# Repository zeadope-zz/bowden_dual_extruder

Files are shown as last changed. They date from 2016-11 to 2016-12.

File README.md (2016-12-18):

# bowden_dual_extruder
For more information check:
http://www.thingiverse.com/thing:1888865 - Bowden dual/quad extrusion extruder (single-nozzle single-drive) + video

This Repo exists so that anyone can enjoy this extruder.

### Printer firmware
In your printer's firmware (Marlin, Repetier or other) make sure you setup a delay for as long as it takes for your servo to move fully.
Also, make sure your printer will execute the servo G-Code on extruder switch.
I have added a working example of my Configuration.h from Repetier-Firmware.
For MarlinFirmware, follow the link above and find BigSteve's solution.

### Cura 15.04.6 - Easy option
For the older version, that still works fine, I have added a Configuration file you can simply load within Cura.
Before that, make sure your printer has 2 extruders in "Machine -> Machine settings... Extruder count [2]".
You will have to change the start2, end2 and pre and post switch G-Code to your printer's settings and Y-merger / Dual load/retract nozzle amount.

### Cura 2.3.1 Custom printer - The hard way but more powerful
I have included a configuration for Cura 2.3.1 that defines a custom printer with multiple extruders.
This also included definitions of these extruders and their specific settings for retraction and priming filament at tool change.
Cura 2.3.1 is awesome since the software allows you to select a material/extruder per STL. Even if you want to print a couple of the same single extrusion STL's you can do so. 
Also you can expand the number of extruders. For now I have set up 4 extruders. Since this Extruder design will allow RAMPS board owners to have 2 extruders stepper motors enabling the use of 4 filaments, instead of just 2 (one extruder per stepper motor).
With the Arduino Due and RAMPS-FD you can have a third extruder stepper motor for a total of 6 filaments.

*For Cura 2.3.1 all you have to do is change the extruder start and end G-Code within the custom printer definition file from Cura 2.3.1 to suit your printer.
And change the start and end G-Code of the extruders definition files from Cura 2.3.1 to suit your retraction and priming distances. This depends on the distance between the tip of the nozzle to the retract resting spot within the filament merger.
Make sure you add a delay on the first line of your extruder end G-Code that is more than your servo delay in ms in the firmware. For instance G-Code would be: "G4 700\n ; rest of Cura EXT# end g-code", if your servo delay is 600 ms in the firmware.
If you do it that way, your G-Code will start 100 ms after the servo has fully engaged the other filament idler. Hope this make any sense.
I have already added this to my Configuration.h and Cura 15.04.6 profile, both available in this repo.*

### Repetier-Firmware
There are a few major brands in the consumer 3D Printing world that use Repetier for multi-extrusion.
The support is awesome in this firmware. Also, I have no choice, since they are the only ones that release a proper firmware for my Arduino Due with RAMPS-FD board. 
I have included the files that were altered in order to set up dual extrusion.
This method allows for up to 10 extruders using only 5 stepper motors.

### More information
See the link above for more information. See the comments tab at that link for my log.

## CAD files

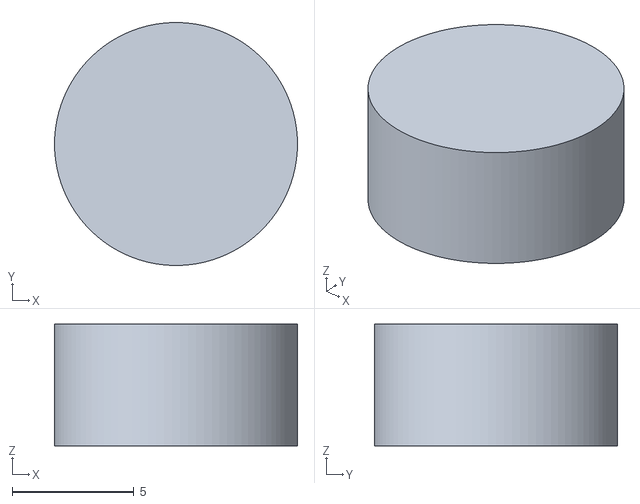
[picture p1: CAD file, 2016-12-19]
stl/cylinder-in-circle/cyl-in-circ.stl
10.0 x 9.99 x 5.00

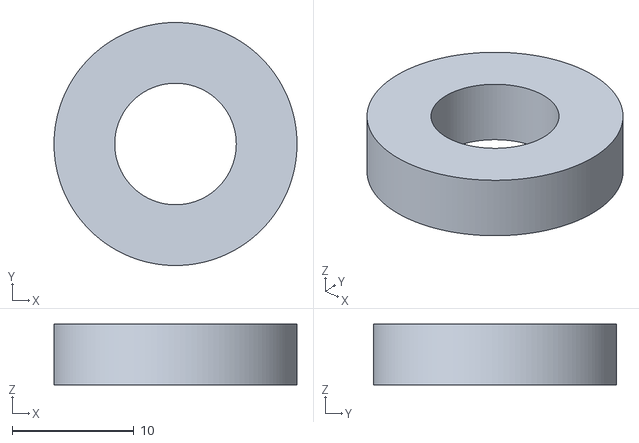
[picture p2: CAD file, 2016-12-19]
stl/cylinder-in-circle/circ-around-cyl.stl
20.0 x 20.0 x 5.00

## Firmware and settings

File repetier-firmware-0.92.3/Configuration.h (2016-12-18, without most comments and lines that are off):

#define CONFIGURATION_H
#define NUM_EXTRUDER 2
#define MOTHERBOARD 403
#include "pins.h"
#define FAN_BOARD_PIN -1
#define BLUETOOTH_SERIAL  -1
#define BLUETOOTH_BAUD  115200
#define MIXING_EXTRUDER 0
#define DRIVE_SYSTEM 0
#define XAXIS_STEPS_PER_MM 320
#define YAXIS_STEPS_PER_MM 320
#define ZAXIS_STEPS_PER_MM 16000
#define EXTRUDER_FAN_COOL_TEMP 50
#define PDM_FOR_EXTRUDER 0
#define PDM_FOR_COOLER 0
#define DECOUPLING_TEST_MAX_HOLD_VARIANCE 20
#define DECOUPLING_TEST_MIN_TEMP_RISE 1
#define KILL_IF_SENSOR_DEFECT 0
#define RETRACT_ON_PAUSE 2
#define PAUSE_START_COMMANDS ""
#define PAUSE_END_COMMANDS ""
#define EXT0_X_OFFSET 0
#define EXT0_Y_OFFSET 0
#define EXT0_STEPS_PER_MM 582 // MK8 // 2986 // WADE
#define EXT0_TEMPSENSOR_TYPE 8
#define EXT0_TEMPSENSOR_PIN TEMP_1_PIN
#define EXT0_HEATER_PIN HEATER_1_PIN
#define EXT0_STEP_PIN ORIG_E0_STEP_PIN
#define EXT0_DIR_PIN ORIG_E0_DIR_PIN
#define EXT0_INVERSE 1 // Single drive changes direction
#define EXT0_ENABLE_PIN E0_ENABLE_PIN
#define EXT0_ENABLE_ON 0
#define EXT0_MAX_FEEDRATE 50
#define EXT0_MAX_START_FEEDRATE 20
#define EXT0_MAX_ACCELERATION 500
#define EXT0_HEAT_MANAGER 1
#define EXT0_WATCHPERIOD 1
#define EXT0_PID_INTEGRAL_DRIVE_MAX 255
#define EXT0_PID_INTEGRAL_DRIVE_MIN 40
#define EXT0_PID_PGAIN_OR_DEAD_TIME 18.77
#define EXT0_PID_I 2.28
#define EXT0_PID_D 38.62
#define EXT0_PID_MAX 255
#define EXT0_ADVANCE_K 0
#define EXT0_ADVANCE_L 0
#define EXT0_ADVANCE_BACKLASH_STEPS 0
#define EXT0_WAIT_RETRACT_TEMP 150
#define EXT0_WAIT_RETRACT_UNITS 2
#define EXT0_SELECT_COMMANDS "M340 P0 S820 R600\nG4 P1000\n" // P=port, S=Servo position in ms EXT0, !R=auto off delay MUST be long enough for servo to reach dest. // Prime settings in slicing software
#define EXT0_DESELECT_COMMANDS "" // Retract settings in slicing software
#define EXT0_EXTRUDER_COOLER_PIN 12
#define EXT0_EXTRUDER_COOLER_SPEED 255 // z3dope 14:48 24-02-2016 reason Sunon fan
#define EXT0_DECOUPLE_TEST_PERIOD 12000
#define EXT0_JAM_PIN -1
#define EXT0_JAM_PULLUP 0
#define EXT1_X_OFFSET EXT0_X_OFFSET
#define EXT1_Y_OFFSET EXT0_Y_OFFSET
#define EXT1_STEPS_PER_MM EXT0_STEPS_PER_MM
#define EXT1_TEMPSENSOR_TYPE EXT0_TEMPSENSOR_TYPE
#define EXT1_TEMPSENSOR_PIN EXT0_TEMPSENSOR_PIN
#define EXT1_HEATER_PIN -1 // Not needed for single-nozzle
#define EXT1_STEP_PIN ORIG_E1_STEP_PIN
#define EXT1_DIR_PIN ORIG_E1_DIR_PIN
#define EXT1_INVERSE 0 // Single drive changes direction
#define EXT1_ENABLE_PIN ORIG_E1_ENABLE_PIN
#define EXT1_ENABLE_ON EXT0_ENABLE_ON
#define EXT1_MAX_FEEDRATE EXT0_MAX_FEEDRATE
#define EXT1_MAX_START_FEEDRATE EXT0_MAX_START_FEEDRATE
#define EXT1_MAX_ACCELERATION EXT0_MAX_ACCELERATION
#define EXT1_HEAT_MANAGER EXT0_HEAT_MANAGER
#define EXT1_WATCHPERIOD EXT0_WATCHPERIOD
#define EXT1_PID_INTEGRAL_DRIVE_MAX EXT0_PID_INTEGRAL_DRIVE_MAX
#define EXT1_PID_INTEGRAL_DRIVE_MIN EXT0_PID_INTEGRAL_DRIVE_MIN
#define EXT1_PID_PGAIN_OR_DEAD_TIME EXT0_PID_PGAIN_OR_DEAD_TIME
#define EXT1_PID_I EXT0_PID_I
#define EXT1_PID_D EXT0_PID_D
#define EXT1_PID_MAX EXT0_PID_MAX
#define EXT1_ADVANCE_K EXT0_ADVANCE_K
#define EXT1_ADVANCE_L EXT0_ADVANCE_L
#define EXT1_ADVANCE_BACKLASH_STEPS EXT0_ADVANCE_BACKLASH_STEPS
#define EXT1_WAIT_RETRACT_TEMP EXT0_WAIT_RETRACT_TEMP
#define EXT1_WAIT_RETRACT_UNITS EXT0_WAIT_RETRACT_UNITS
#define EXT1_SELECT_COMMANDS "M340 P0 S2250 R600\nG4 P1000\n" // P=port, S=Servo position in ms EXT0, !R=auto off delay MUST be long enough for servo to reach dest. // Prime settings in slicing software
#define EXT1_DESELECT_COMMANDS "" // Retract settings in slicing software
#define EXT1_EXTRUDER_COOLER_PIN EXT0_EXTRUDER_COOLER_PIN
#define EXT1_EXTRUDER_COOLER_SPEED EXT0_EXTRUDER_COOLER_SPEED
#define EXT1_DECOUPLE_TEST_PERIOD -1 // Not needed for single-nozzle
#define EXT1_JAM_PIN EXT0_JAM_PIN
#define EXT1_JAM_PULLUP EXT0_JAM_PULLUP
#define FEATURE_RETRACTION 1
#define AUTORETRACT_ENABLED 0
#define RETRACTION_LENGTH 3
#define RETRACTION_LONG_LENGTH 13
#define RETRACTION_SPEED 40
#define RETRACTION_Z_LIFT 0
#define RETRACTION_UNDO_EXTRA_LENGTH 0
#define RETRACTION_UNDO_EXTRA_LONG_LENGTH 0
#define RETRACTION_UNDO_SPEED 20
#define FILAMENTCHANGE_X_POS 0
#define FILAMENTCHANGE_Y_POS 0
#define FILAMENTCHANGE_Z_ADD  2
#define FILAMENTCHANGE_REHOME 1
#define FILAMENTCHANGE_SHORTRETRACT 5
#define FILAMENTCHANGE_LONGRETRACT 50
#define JAM_STEPS 220
#define JAM_SLOWDOWN_STEPS 320
#define JAM_SLOWDOWN_TO 70
#define JAM_ERROR_STEPS 500
#define JAM_MIN_STEPS 10
#define JAM_ACTION 1
#define RETRACT_DURING_HEATUP true
#define PID_CONTROL_RANGE 20
#define SKIP_M109_IF_WITHIN 2
#define SCALE_PID_TO_MAX 0
#define TEMP_HYSTERESIS 0
#define EXTRUDE_MAXLENGTH 160
#define NUM_TEMPS_USERTHERMISTOR0 0
#define USER_THERMISTORTABLE0 {}
#define NUM_TEMPS_USERTHERMISTOR1 0
#define USER_THERMISTORTABLE1 {}
#define NUM_TEMPS_USERTHERMISTOR2 0
#define USER_THERMISTORTABLE2 {}
#define GENERIC_THERM_VREF 5
#define GENERIC_THERM_NUM_ENTRIES 33
#define HEATER_PWM_SPEED 0
#define HAVE_HEATED_BED 1
#define HEATED_BED_MAX_TEMP 120
#define SKIP_M190_IF_WITHIN 3
#define HEATED_BED_SENSOR_TYPE 1
#define HEATED_BED_SENSOR_PIN TEMP_0_PIN
#define HEATED_BED_HEATER_PIN HEATER_0_PIN
#define HEATED_BED_SET_INTERVAL 5000
#define HEATED_BED_HEAT_MANAGER 0
#define HEATED_BED_PID_INTEGRAL_DRIVE_MAX 255
#define HEATED_BED_PID_INTEGRAL_DRIVE_MIN 80
#define HEATED_BED_PID_PGAIN_OR_DEAD_TIME   164.3
#define HEATED_BED_PID_IGAIN   10.69
#define HEATED_BED_PID_DGAIN 635.96
#define HEATED_BED_PID_MAX 255
#define HEATED_BED_DECOUPLE_TEST_PERIOD 300000 // z3Dope 20160518 20:07
#define MIN_EXTRUDER_TEMP 170
#define MAXTEMP 275
#define MIN_DEFECT_TEMPERATURE -10
#define MAX_DEFECT_TEMPERATURE 300
#define ENDSTOP_PULLUP_X_MIN true
#define ENDSTOP_X_MIN_INVERTING true
#define MIN_HARDWARE_ENDSTOP_X true
#define ENDSTOP_PULLUP_Y_MIN true
#define ENDSTOP_Y_MIN_INVERTING true
#define MIN_HARDWARE_ENDSTOP_Y true
#define ENDSTOP_PULLUP_Z_MIN false
#define ENDSTOP_Z_MIN_INVERTING true
#define MIN_HARDWARE_ENDSTOP_Z false // z3Dope
#define ENDSTOP_PULLUP_X_MAX true
#define ENDSTOP_X_MAX_INVERTING false
#define MAX_HARDWARE_ENDSTOP_X false
#define ENDSTOP_PULLUP_Y_MAX true
#define ENDSTOP_Y_MAX_INVERTING false
#define MAX_HARDWARE_ENDSTOP_Y false
#define ENDSTOP_PULLUP_Z_MAX true
#define ENDSTOP_Z_MAX_INVERTING true
#define MAX_HARDWARE_ENDSTOP_Z true
#define max_software_endstop_r true
#define min_software_endstop_x false
#define min_software_endstop_y false
#define min_software_endstop_z false
#define max_software_endstop_x true
#define max_software_endstop_y true
#define max_software_endstop_z false // z3Dope 14:45 24-02-2016
#define ENDSTOP_X_BACK_MOVE 5
#define ENDSTOP_Y_BACK_MOVE 5
#define ENDSTOP_Z_BACK_MOVE 5 // 2 z3Dope
#define ENDSTOP_X_RETEST_REDUCTION_FACTOR 3
#define ENDSTOP_Y_RETEST_REDUCTION_FACTOR 3
#define ENDSTOP_Z_RETEST_REDUCTION_FACTOR 3
#define ENDSTOP_X_BACK_ON_HOME 1
#define ENDSTOP_Y_BACK_ON_HOME 1
#define ENDSTOP_Z_BACK_ON_HOME 0
#define ALWAYS_CHECK_ENDSTOPS 0
#define X_ENABLE_ON 0
#define Y_ENABLE_ON 0
#define Z_ENABLE_ON 0
#define DISABLE_X 0
#define DISABLE_Y 0
#define DISABLE_Z 0
#define DISABLE_E 0
#define INVERT_X_DIR 1
#define INVERT_Y_DIR 0
#define INVERT_Z_DIR 1
#define X_HOME_DIR -1
#define Y_HOME_DIR -1
#define Z_HOME_DIR 1 // -1 z3Dope
#define X_MAX_LENGTH 200
#define Y_MAX_LENGTH 200
#define Z_MAX_LENGTH 180
#define X_MIN_POS 0
#define Y_MIN_POS 0
#define Z_MIN_POS 0
#define DISTORTION_CORRECTION 1
#define DISTORTION_CORRECTION_POINTS 5
#define DISTORTION_CORRECTION_R 100
#define DISTORTION_PERMANENT 1
#define DISTORTION_UPDATE_FREQUENCY 15
#define DISTORTION_START_DEGRADE 0.5
#define DISTORTION_END_HEIGHT 1
#define DISTORTION_EXTRAPOLATE_CORNERS 0
#define FEATURE_BABYSTEPPING 1
#define BABYSTEP_MULTIPLICATOR 1
#define DELTA_SEGMENTS_PER_SECOND_PRINT 180 // Move accurate setting for print moves
#define DELTA_SEGMENTS_PER_SECOND_MOVE 70 // Less accurate setting for other moves
#define DELTA_HOME_ON_POWER 0
#define DELTASEGMENTS_PER_PRINTLINE 24
#define STEPPER_INACTIVE_TIME 360L
#define MAX_INACTIVE_TIME 0L
#define MAX_FEEDRATE_X 200
#define MAX_FEEDRATE_Y 200
#define MAX_FEEDRATE_Z 5 // 4 z3Dope z3Dope 2016-1-17
#define HOMING_FEEDRATE_X 50 // 40 z3Dope
#define HOMING_FEEDRATE_Y 50 // 40 z3Dope
#define HOMING_FEEDRATE_Z 4 // 2 z3Dope
#define HOMING_ORDER HOME_ORDER_YXZ
#define ENABLE_BACKLASH_COMPENSATION 0
#define X_BACKLASH 0
#define Y_BACKLASH 0
#define Z_BACKLASH 0
#define RAMP_ACCELERATION 1
#define STEPPER_HIGH_DELAY 2 // 0 z3Dope 2015-06-24 14:56
#define DIRECTION_DELAY 0// 1 // 0 z3Dope 2016-1-17
#define STEP_DOUBLER_FREQUENCY 90000 // 12000 repetier GitHub issue 2015-06-24 16:13
#define ALLOW_QUADSTEPPING 1
#define DOUBLE_STEP_DELAY 1 // time in microseconds
#define MAX_HALFSTEP_INTERVAL 1999
#define MAX_ACCELERATION_UNITS_PER_SQ_SECOND_X 1000
#define MAX_ACCELERATION_UNITS_PER_SQ_SECOND_Y 1000
#define MAX_ACCELERATION_UNITS_PER_SQ_SECOND_Z 20
#define MAX_TRAVEL_ACCELERATION_UNITS_PER_SQ_SECOND_X 1000
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

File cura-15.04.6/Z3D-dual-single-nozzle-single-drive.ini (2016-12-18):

[profile]
layer_height = 0.3
wall_thickness = 0.8
retraction_enable = True
solid_layer_thickness = 0.9
fill_density = 25
print_speed = 50
print_temperature = 240
print_temperature2 = 0
print_temperature3 = 0
print_temperature4 = 0
print_temperature5 = 0
print_bed_temperature = 95
support = None
platform_adhesion = None
support_dual_extrusion = Both
wipe_tower = True
wipe_tower_volume = 30
ooze_shield = False
filament_diameter = 1.75
filament_diameter2 = 0
filament_diameter3 = 0
filament_diameter4 = 0
filament_diameter5 = 0
filament_flow = 100.0
nozzle_size = 0.4
retraction_speed = 45
retraction_amount = 4.5
retraction_dual_amount = 16.5
retraction_min_travel = 1.5
retraction_combing = All
retraction_minimal_extrusion = 0.02
retraction_hop = 0.075
bottom_thickness = 0.3
layer0_width_factor = 120
object_sink = 0.0
overlap_dual = 0.15
travel_speed = 50
bottom_layer_speed = 20
infill_speed = 0.0
solidarea_speed = 0.0
inset0_speed = 0.0
insetx_speed = 0.0
cool_min_layer_time = 10
fan_enabled = True
skirt_line_count = 5
skirt_gap = 3.0
skirt_minimal_length = 150.0
fan_full_height = 0.5
fan_speed = 100
fan_speed_max = 100
cool_min_feedrate = 10
cool_head_lift = False
solid_top = True
solid_bottom = True
fill_overlap = 15
perimeter_before_infill = False
support_type = Lines
support_angle = 60
support_fill_rate = 15
support_xy_distance = 0.7
support_z_distance = 0.15
spiralize = False
simple_mode = False
brim_line_count = 20
raft_margin = 5.0
raft_line_spacing = 3.0
raft_base_thickness = 0.3
raft_base_linewidth = 1.0
raft_interface_thickness = 0.27
raft_interface_linewidth = 0.4
raft_airgap_all = 0.0
raft_airgap = 0.22
raft_surface_layers = 2
raft_surface_thickness = 0.27
raft_surface_linewidth = 0.4
fix_horrible_union_all_type_a = True
fix_horrible_union_all_type_b = False
fix_horrible_use_open_bits = False
fix_horrible_extensive_stitching = False
plugin_config = 
object_center_x = -1
object_center_y = -1

[alterations]
start.gcode = ;Sliced at: {day} {date} {time}
	;Basic settings: Layer height: {layer_height} Walls: {wall_thickness} Fill: {fill_density}
	;Print time: {print_time}
	;Filament used: {filament_amount}m {filament_weight}g
	;Filament cost: {filament_cost}
	;M190 S{print_bed_temperature} ;Uncomment to add your own bed temperature line
	;M109 S{print_temperature} ;Uncomment to add your own temperature line
	G21        ;metric values
	G90        ;absolute positioning
	M82        ;set extruder to absolute mode
	M107       ;start with the fan off
	G28 X0 Y0  ;move X/Y to min endstops
	;G28 Z0     ;move Z to min endstops
	; Auto bed tramming
	G1 F4000 X100 Y100 		;move X/Y to center
	G30
	G32;
	G1 Z15.0 F{travel_speed} ;move the platform down 15mm
	G92 E0                  ;zero the extruded length
	G1 F200 E3              ;extrude 3mm of feed stock
	G92 E0                  ;zero the extruded length again
	G1 F{travel_speed}
	;Put printing message on LCD screen
	M117 Printing...
end.gcode = ;End GCode
	M104 S0                     ;extruder heater off
	M140 S0                     ;heated bed heater off (if you have it)
	G91                                    ;relative positioning
	G1 E-1 F300                            ;retract the filament a bit before lifting the nozzle, to release some of the pressure
	G1 Z+0.5 E-5 X-20 Y-20 F{travel_speed} ;move Z up a bit and retract filament even more
	G28 X0 Y0                              ;move X/Y to min endstops, so the head is out of the way
	M84                         ;steppers off
	G90                         ;absolute positioning
	;{profile_string}
start2.gcode = ;Sliced at: {day} {date} {time}
	;Basic settings: Layer height: {layer_height} Walls: {wall_thickness} Fill: {fill_density}
	;Print time: {print_time}
	;Filament used: {filament_amount}m {filament_weight}g
	;Filament cost: {filament_cost}
	;M190 S{print_bed_temperature} ;Uncomment to add your own bed temperature line
	;M104 S{print_temperature} ;Uncomment to add your own temperature line
	;M109 T1 S{print_temperature2} ;Uncomment to add your own temperature line
	;M109 T0 S{print_temperature} ;Uncomment to add your own temperature line
	G21        ;metric values
	G90        ;absolute positioning
	M107       ;start with the fan off
	G28 X0 Y0  ;move X/Y to min endstops
	;G28 Z0     ;move Z to min endstops
	; Z3D Auto bed tramming
	G1 F4000 X100 Y100 		 ;move X/Y to center
	G30
	G32;
	G1 Z15.0 F{travel_speed} ;move the platform down 15mm
	T1                       ;Switch to the 2nd extruder
	G92 E0                   ;zero the extruded length
	;G1 F200 E10             ;extrude 10mm of feed stock
	;G92 E0                  ;zero the extruded length again
	;G1 F200 E-{retraction_dual_amount}
	T0                       ;Switch to the first extruder
	;G92 E0                  ;zero the extruded length
	;G1 F200 E10             ;extrude 10mm of feed stock
	;G92 E0                  ;zero the extruded length again
	G92 E0					 ; Z3D extrude since last print
	G1 E135 F10000
	G92 E0
	G1 F{travel_speed}
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

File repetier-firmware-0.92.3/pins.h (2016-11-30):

#ifndef PINS_H
#define PINS_H


/*
The board assignment defines the capabilities of the motherboard and the used pins.
Each board definition follows the following scheme:

CPU_ARCH
  ARCH_AVR for AVR based boards
  ARCH_ARM for all arm based boards

STEPPER_CURRENT_CONTROL
  CURRENT_CONTROL_MANUAL  1  // mechanical poti, default if not defined
  CURRENT_CONTROL_DIGIPOT 2  // Use a digipot like RAMBO does
  CURRENT_CONTROL_LTC2600 3  // Use LTC2600 like Foltyn 3D Master

*/

#define ARCH_AVR 1
#define ARCH_ARM 2
#define CPU_ARCH ARCH_ARM
#define CURRENT_CONTROL_MANUAL  1  // mechanical poti, default if not defined
#define CURRENT_CONTROL_DIGIPOT 2  // Use a digipot like RAMBO does
#define CURRENT_CONTROL_LTC2600 3  // Use LTC2600 like Foltyn 3D Master



#if MOTHERBOARD == 401
#ifndef __SAM3X8E__
#error Oops!  Make sure you have 'Arduino Due' selected from the 'Tools -> Boards' menu.
#endif

#define KNOWN_BOARD
#define CPU_ARCH ARCH_ARM
/*****************************************************************
* Arduino Due Pin Assignments
******************************************************************/

#define ORIG_X_STEP_PIN     54  // A0
#define ORIG_X_DIR_PIN      55  // A1
#define ORIG_X_MIN_PIN      3
#define ORIG_X_MAX_PIN      2
#define ORIG_X_ENABLE_PIN   38

#define ORIG_Y_STEP_PIN     60  // A6 
#define ORIG_Y_DIR_PIN      61  // A7
#define ORIG_Y_MIN_PIN      14
#define ORIG_Y_MAX_PIN      15
#define ORIG_Y_ENABLE_PIN   56  // A2

#define ORIG_Z_STEP_PIN     46
#define ORIG_Z_DIR_PIN      48
#define ORIG_Z_MIN_PIN      18
#define ORIG_Z_MAX_PIN      19
#define ORIG_Z_ENABLE_PIN   62  // A8

// Note that on the Due pin A0 on the board is channel 2 on the ARM chip
#define HEATER_0_PIN   10
#define TEMP_0_PIN     11  // Due analog pin #
#define HEATER_1_PIN   8
#define TEMP_1_PIN     12  // Due analog pin #
#define HEATER_2_PIN   9
#define TEMP_2_PIN     13  // Due analog pin #

#define ORIG_E0_STEP_PIN    26
#define ORIG_E0_DIR_PIN     28
#define ORIG_E0_ENABLE_PIN  24

#define ORIG_E1_STEP_PIN    36
#define ORIG_E1_DIR_PIN     34
#define ORIG_E1_ENABLE_PIN  40

#define SDPOWER 	   -1
#define SDSS		   53 // 10 if using HW SPI. 53 if using SW SPI
#define LED_PIN 	   13
#define ORIG_FAN_PIN 	   -1
#define ORIG_PS_ON_PIN      12
#define KILL_PIN	   -1
#define SUICIDE_PIN    -1  //PIN that has to be turned on right after start, to keep power flowing.


#define SDA_PIN 				20  	// 20 or 70
#define SCL_PIN 				21  	// 21 or 71


#define E0_PINS ORIG_E0_STEP_PIN,ORIG_E0_DIR_PIN,ORIG_E0_ENABLE_PIN,
#define E1_PINS ORIG_E1_STEP_PIN,ORIG_E1_DIR_PIN,ORIG_E1_ENABLE_PIN,

#define TWI_CLOCK_FREQ          400000
// see eeprom device data sheet for the following values, these are for 24xx256
#define EEPROM_SERIAL_ADDR      0x50   // 7 bit i2c address (without R/W bit)
#define EEPROM_PAGE_SIZE        64     // page write buffer size
#define EEPROM_PAGE_WRITE_TIME  7      // page write time in milliseconds (docs say 5ms but that is too short)
// TWI_MMR_IADRSZ_1_BYTE for 1 byte, or TWI_MMR_IADRSZ_2_BYTE for 2 byte
#define EEPROM_ADDRSZ_BYTES     TWI_MMR_IADRSZ_2_BYTE
#define EEPROM_AVAILABLE 1
#endif

// RADDS Board
// http://www.dr-henschke.de/RADDS_due.html
#if MOTHERBOARD == 402
#ifndef __SAM3X8E__
#error Oops!  Make sure you have 'Arduino Due' selected from the 'Tools -> Boards' menu.
#endif

#define KNOWN_BOARD
#define CPU_ARCH ARCH_ARM
/*****************************************************************
* Arduino Due Pin Assignments
******************************************************************/

#define ORIG_X_STEP_PIN     24
#define ORIG_X_DIR_PIN      23
#define ORIG_X_MIN_PIN      28
#define ORIG_X_MAX_PIN      34
#define ORIG_X_ENABLE_PIN   26

#define ORIG_Y_STEP_PIN     17 
#define ORIG_Y_DIR_PIN      16
#define ORIG_Y_MIN_PIN      30
#define ORIG_Y_MAX_PIN      36
#define ORIG_Y_ENABLE_PIN   22

#define ORIG_Z_STEP_PIN     2
#define ORIG_Z_DIR_PIN      3
#define ORIG_Z_MIN_PIN      32
#define ORIG_Z_MAX_PIN      38
#define ORIG_Z_ENABLE_PIN   15

// Note that on the Due pin A0 on the board is channel 2 on the ARM chip
#define HEATER_0_PIN     13
#define TEMP_0_PIN       7 // Due analog pin #54
#define HEATER_1_PIN     7 
#define TEMP_1_PIN       3 // Due analog pin #58
#define HEATER_2_PIN     12
#define TEMP_2_PIN       6 // Due analog pin #55
#define HEATER_3_PIN     11
#define TEMP_3_PIN       5 // Due analog pin #56
#define TEMP_4_PIN       4 // Due analog pin #57

#define ORIG_E0_STEP_PIN    61 // A7
#define ORIG_E0_DIR_PIN     60 // A6
#define ORIG_E0_ENABLE_PIN  62 // A8

#define ORIG_E1_STEP_PIN    64 // A10
#define ORIG_E1_DIR_PIN     63 // A9
#define ORIG_E1_ENABLE_PIN  65 // A11

#define ORIG_E2_STEP_PIN    51
#define ORIG_E2_DIR_PIN     53
#define ORIG_E2_ENABLE_PIN  49

#define ORIG_E3_STEP_PIN    35
#define ORIG_E3_DIR_PIN     33
#define ORIG_E3_ENABLE_PIN  37

#define ORIG_E4_STEP_PIN    29
#define ORIG_E4_DIR_PIN     27
#define ORIG_E4_ENABLE_PIN  31
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

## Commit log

2016-11-30 Changed README and added Cura and Repetier-Firmware configuration files
    [Configuration.h]
2016-12-15 swapped servo positions between EXT1 and EX0
    [Configuration.h]
2016-12-18 Improved control no more skipping servo G-Code
    Improved servo control by adding R600 to servo G-Code to EXT0_SELECT_COMMANDS and EXT1_SELECT_COMMANDS. The parameter R is described as auto off in milliseconds according to Repetier documentation.
    [Configuration.h]
2016-12-19 Added handy G-code incase in need of retract safely if there was a problem with print job
2016-12-19 Added handy dual .stl I used to calibrate single-nozzle extruder
    [circ-around-cyl.stl, cyl-in-circ.stl]

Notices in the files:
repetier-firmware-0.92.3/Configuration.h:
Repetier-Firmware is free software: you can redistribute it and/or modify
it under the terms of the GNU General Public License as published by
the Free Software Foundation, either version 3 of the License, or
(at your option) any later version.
